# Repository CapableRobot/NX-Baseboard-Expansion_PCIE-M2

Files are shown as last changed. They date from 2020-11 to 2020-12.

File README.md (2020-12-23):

# NX Baseboard Expansion : PCIe m2 E-Key

This repository holds the open-source files for the PCIe m2 E-Key add-on to the NX Baseboard.  The [NX Baseboard](https://github.com/antmicro/jetson-nano-baseboard) is also open-source, is designed by Antmicro, and is [sold by Capable Robot Components](https://capablerobot.com/products/nx-baseboard/).

PCIe m2 E-Key PCBA

Assembled and tested PCBAs are available for purchase on the [Capable Robot website](https://capablerobot.com/products/nx-baseboard/).

The NX PCIe m.2 E Key PCB provides a standard interface to the NVIDIA NX's PCIe x1 bus, which is exposed on the NX Baseboard via a 10-pin FFC connector. Board specifications:

- m.2 E-Key (PCIe + USB), 2230 size. This is commonly used for WIFI modules like the Intel 8265.
- PCIe x1 interface and 3.3v power are connected to the Host via a 10-pin 0.5mm flex cable.
- USB interface exposed via micro-USB port, allowing USB-specific functionality of the installed card (like Bluetooth) to be used if cabled to the Host. With USB connected, a local 5v to 3.3v regulator can be used in lieu of the 3.3v input on the FFC connector.

Hole spacing on the PCB and location of the flex connector matches that of the NX Baseboard, allowing it to be assembled onto the bottom of the Baseboard.

Any WIFI module that supports m.2 E Key 2230 size can be used with the PCB. We recommend (and stock) the Intel 8265 due to built-in support within NVIDIA Jetpack BSPs.

## License Information

| **Type** | **License** |
| --- | --- |
| Hardware | Copyright Capable Robot Components 2020 <br><br>This source describes Open Hardware and is licensed under the [CERN-OHL-P v2](https://ohwr.org/cern_ohl_p_v2.txt). <br/><br/> You may redistribute and modify this documentation and make products using it under the terms of the [CERN-OHL-P v2](https:/cern.ch/cern-ohl). This documentation is distributed WITHOUT ANY EXPRESS OR IMPLIED WARRANTY, INCLUDING OF MERCHANTABILITY, SATISFACTORY QUALITY AND FITNESS FOR A PARTICULAR PURPOSE. Please see the CERN-OHL-P v2 for applicable conditions |
| Software | NA |
| Documentation | [Creative Commons Attribution-ShareAlike](https://creativecommons.org/licenses/by-sa/4.0/) License |

More detailed information about the CERN License is available in the [license](license) folder and on the [CERN website](https://ohwr.org/project/cernohl/wikis/home).

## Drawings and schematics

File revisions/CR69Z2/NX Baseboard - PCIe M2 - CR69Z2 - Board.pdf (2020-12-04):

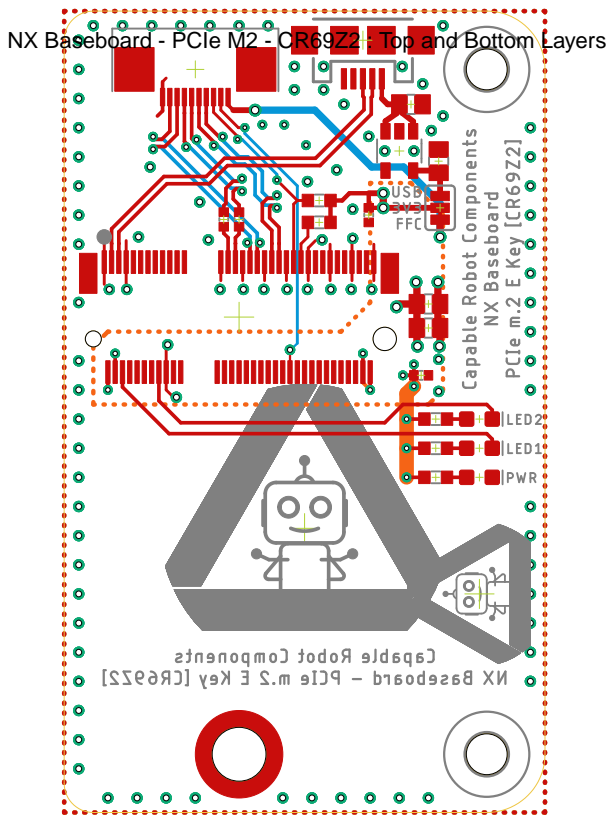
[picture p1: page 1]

NX Baseboard - PCIe M2 - CR69Z2 : Top and Bottom Layers

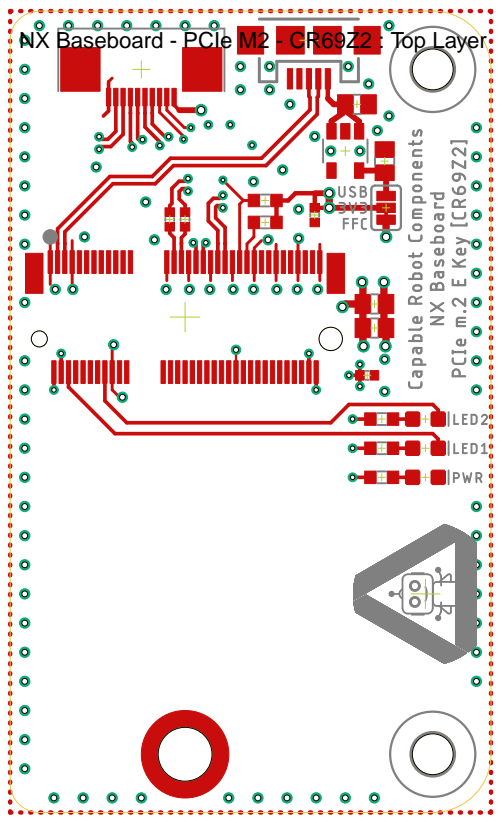
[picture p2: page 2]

NX Baseboard - PCIe M2 - CR69Z2 : Top Layer

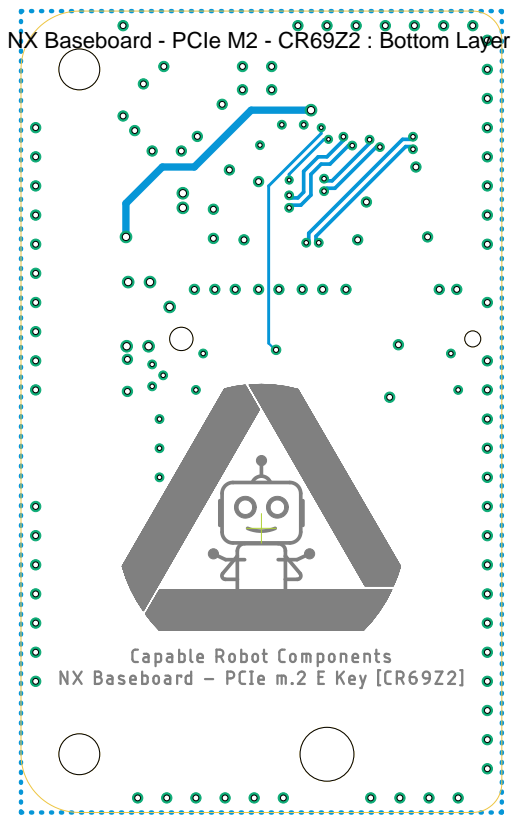
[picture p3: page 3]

NX Baseboard - PCIe M2 - CR69Z2 : Bottom Layer

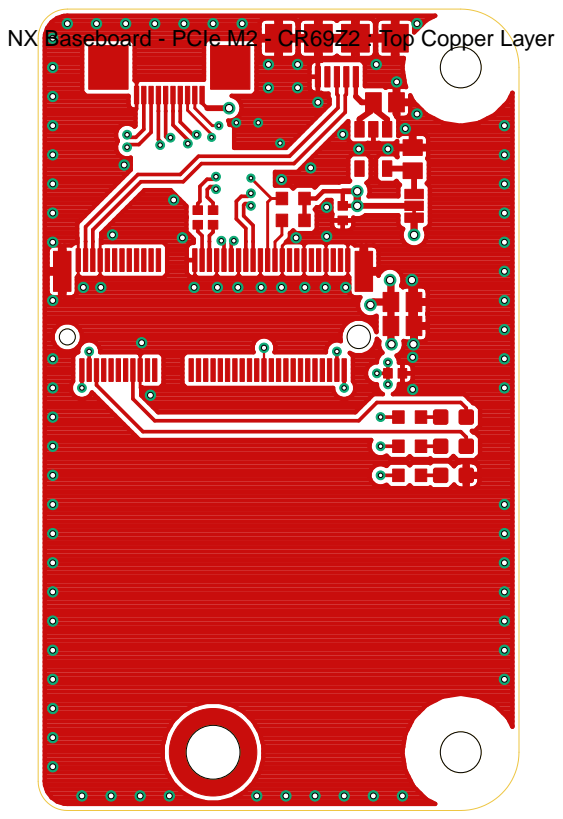
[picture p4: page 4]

NX Baseboard - PCIe M2 - CR69Z2 : Top Copper Layer

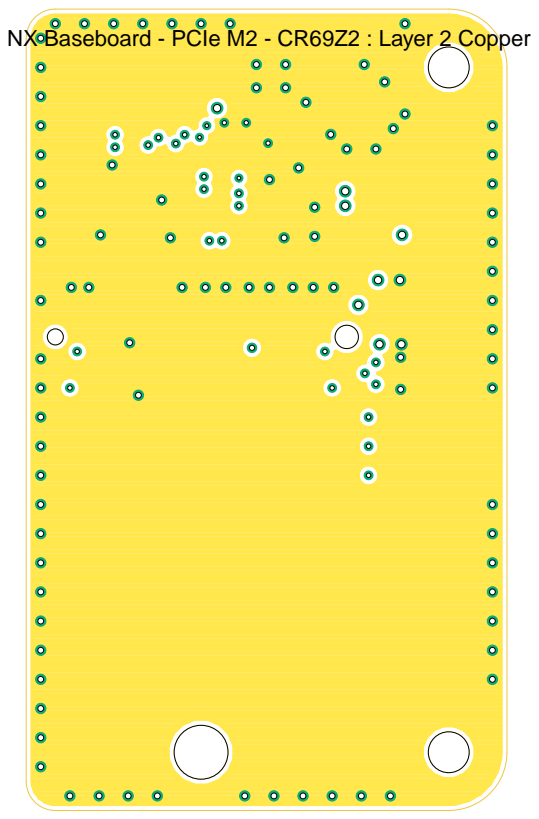
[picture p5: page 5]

NX Baseboard - PCIe M2 - CR69Z2 : Layer 2 Copper

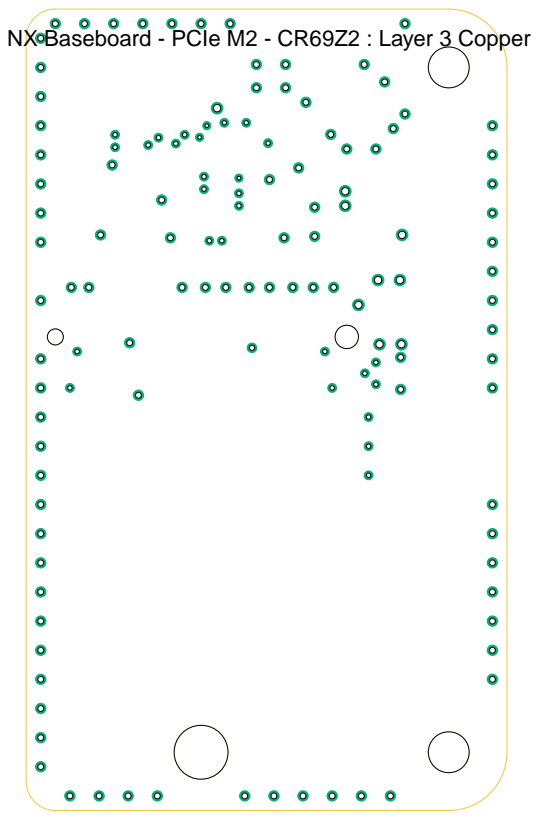
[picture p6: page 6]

NX Baseboard - PCIe M2 - CR69Z2 : Layer 3 Copper

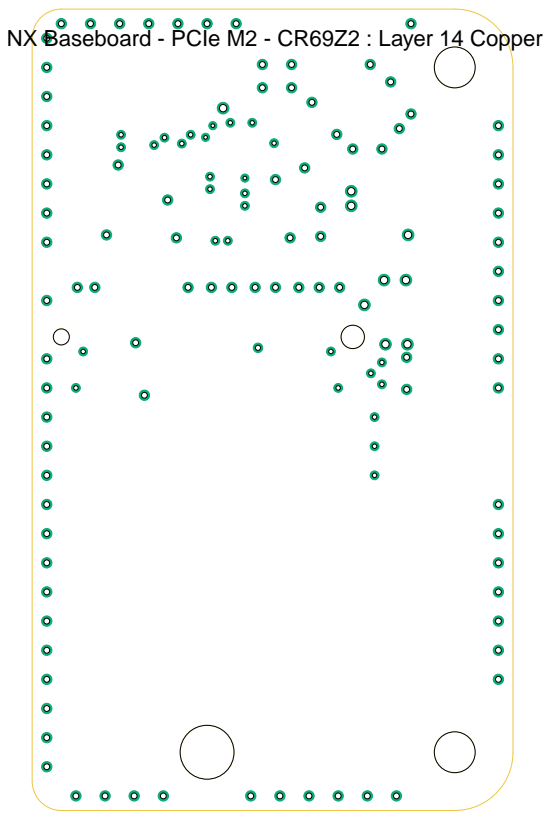
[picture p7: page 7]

NX Baseboard - PCIe M2 - CR69Z2 : Layer 14 Copper

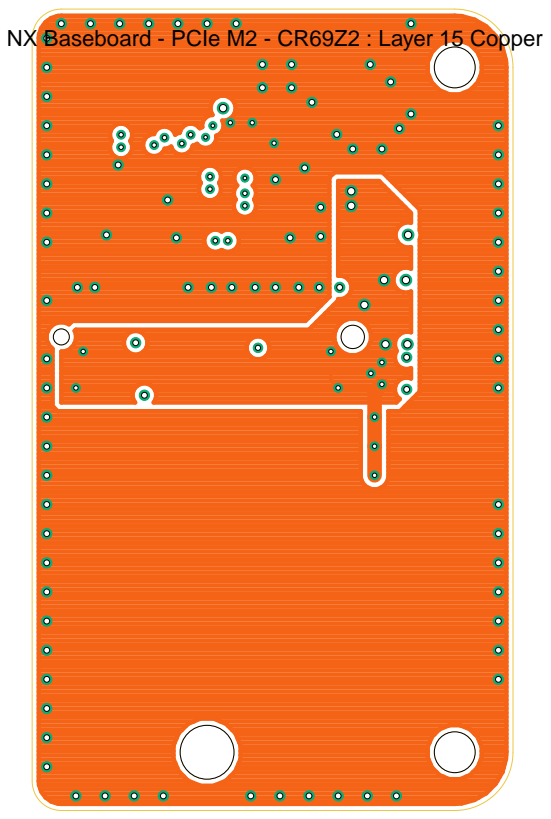
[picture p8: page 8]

NX Baseboard - PCIe M2 - CR69Z2 : Layer 15 Copper

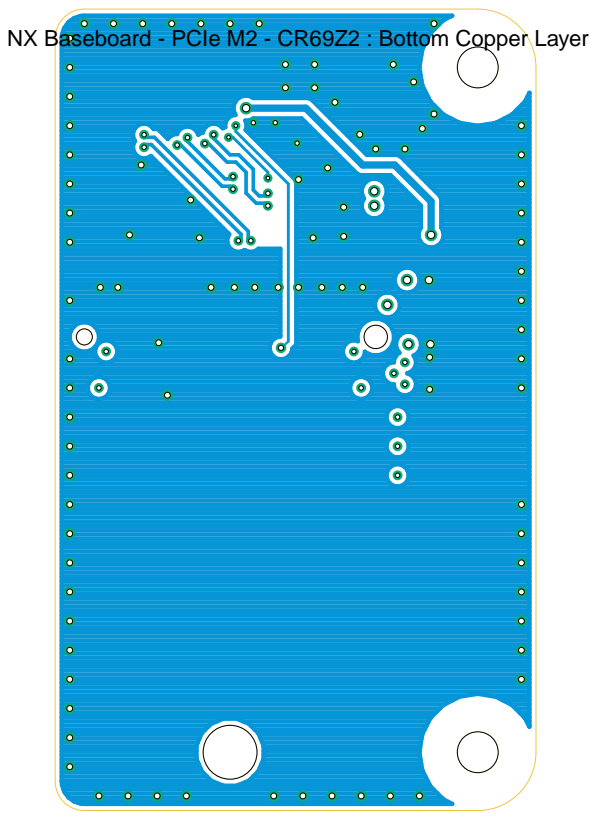
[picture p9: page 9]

NX Baseboard - PCIe M2 - CR69Z2 : Bottom Copper Layer

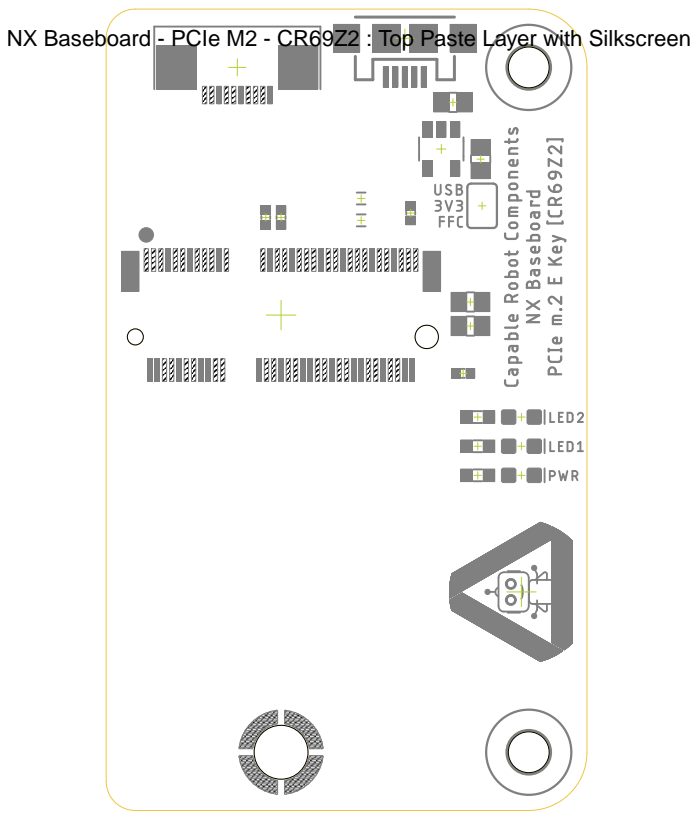
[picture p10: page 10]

NX Baseboard - PCIe M2 - CR69Z2 : Top Paste Layer with Silkscreen

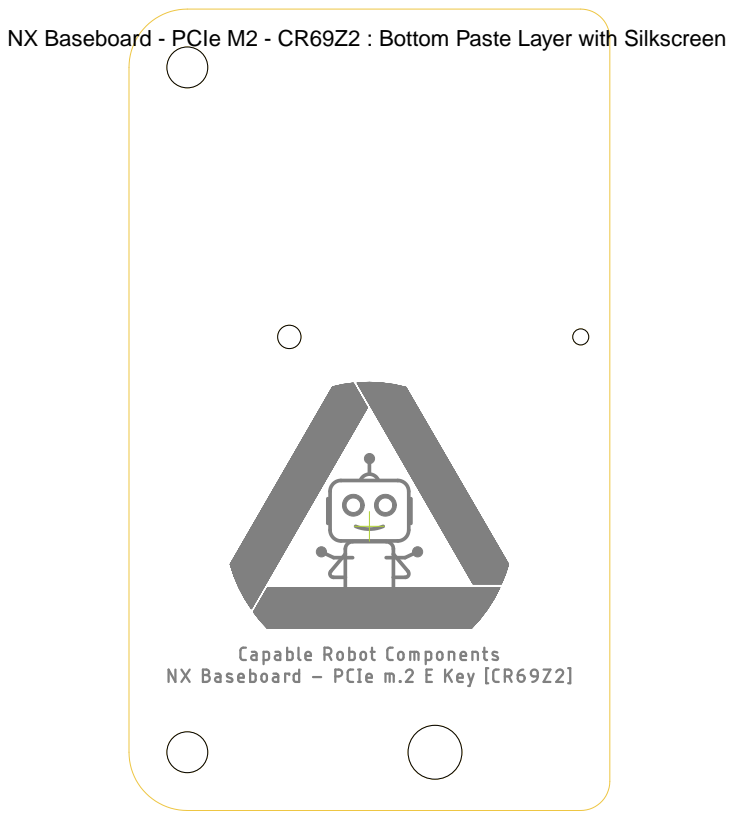
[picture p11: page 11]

NX Baseboard - PCIe M2 - CR69Z2 : Bottom Paste Layer with Silkscreen

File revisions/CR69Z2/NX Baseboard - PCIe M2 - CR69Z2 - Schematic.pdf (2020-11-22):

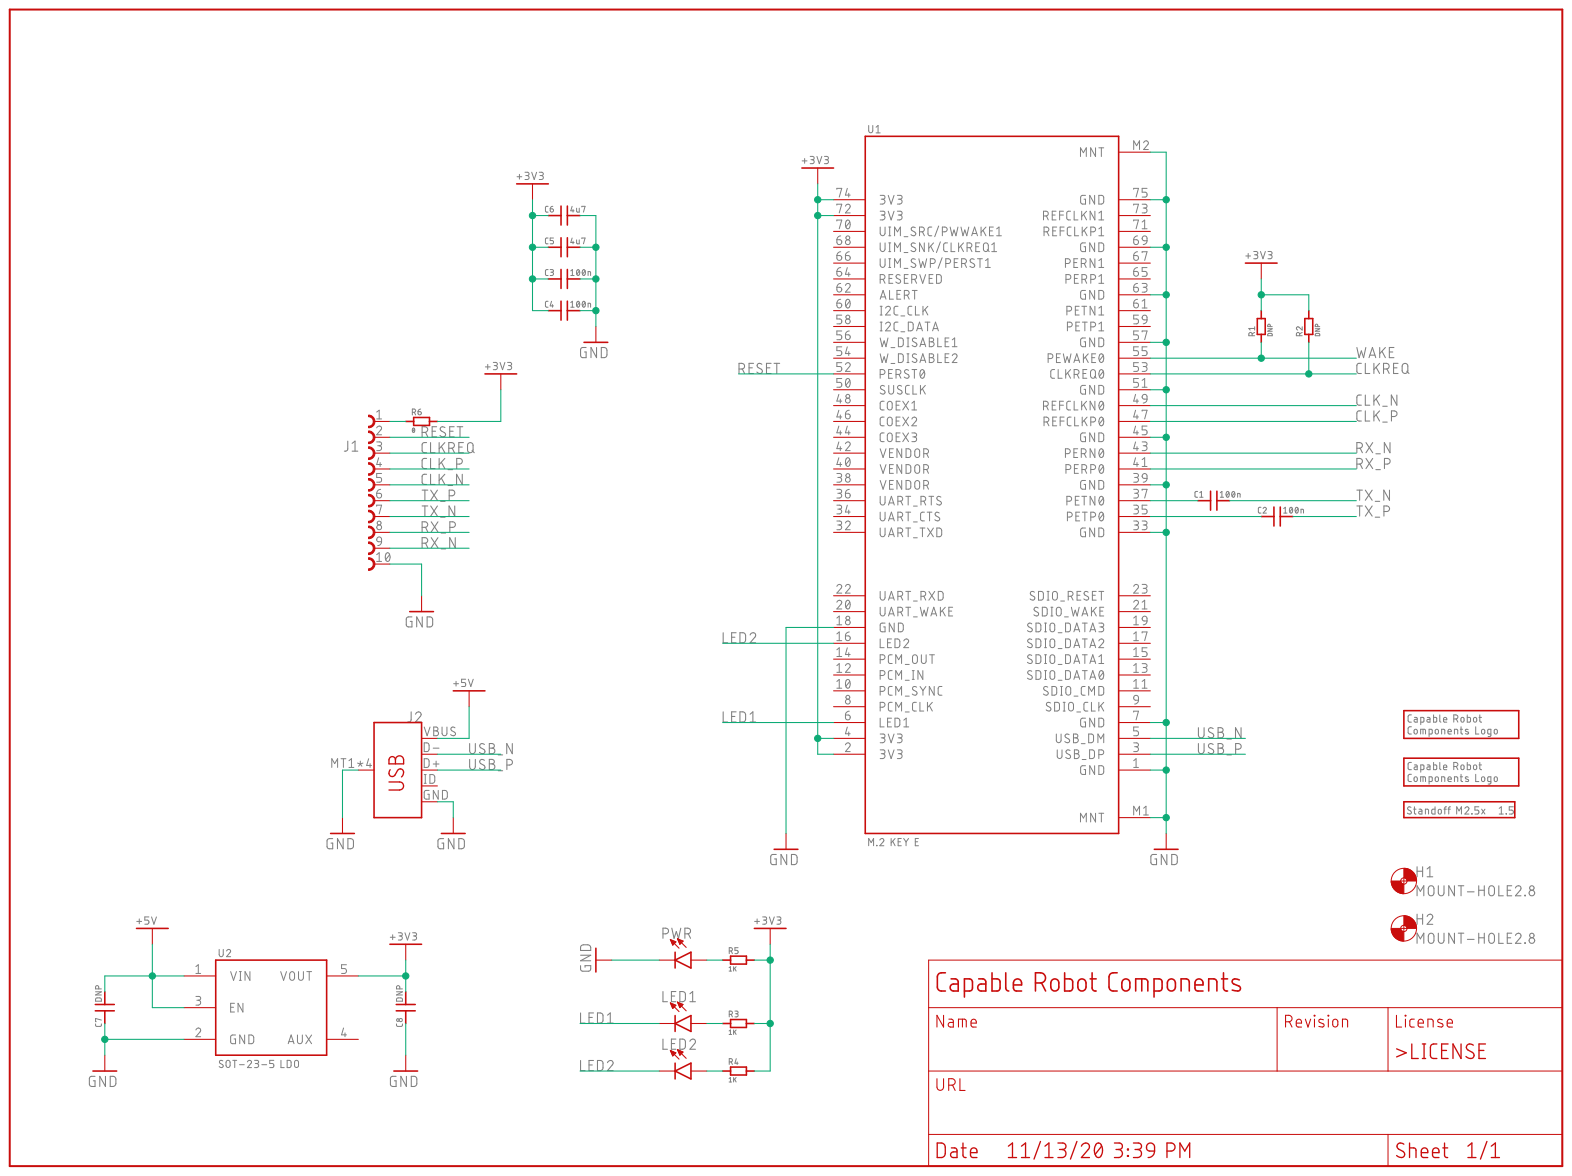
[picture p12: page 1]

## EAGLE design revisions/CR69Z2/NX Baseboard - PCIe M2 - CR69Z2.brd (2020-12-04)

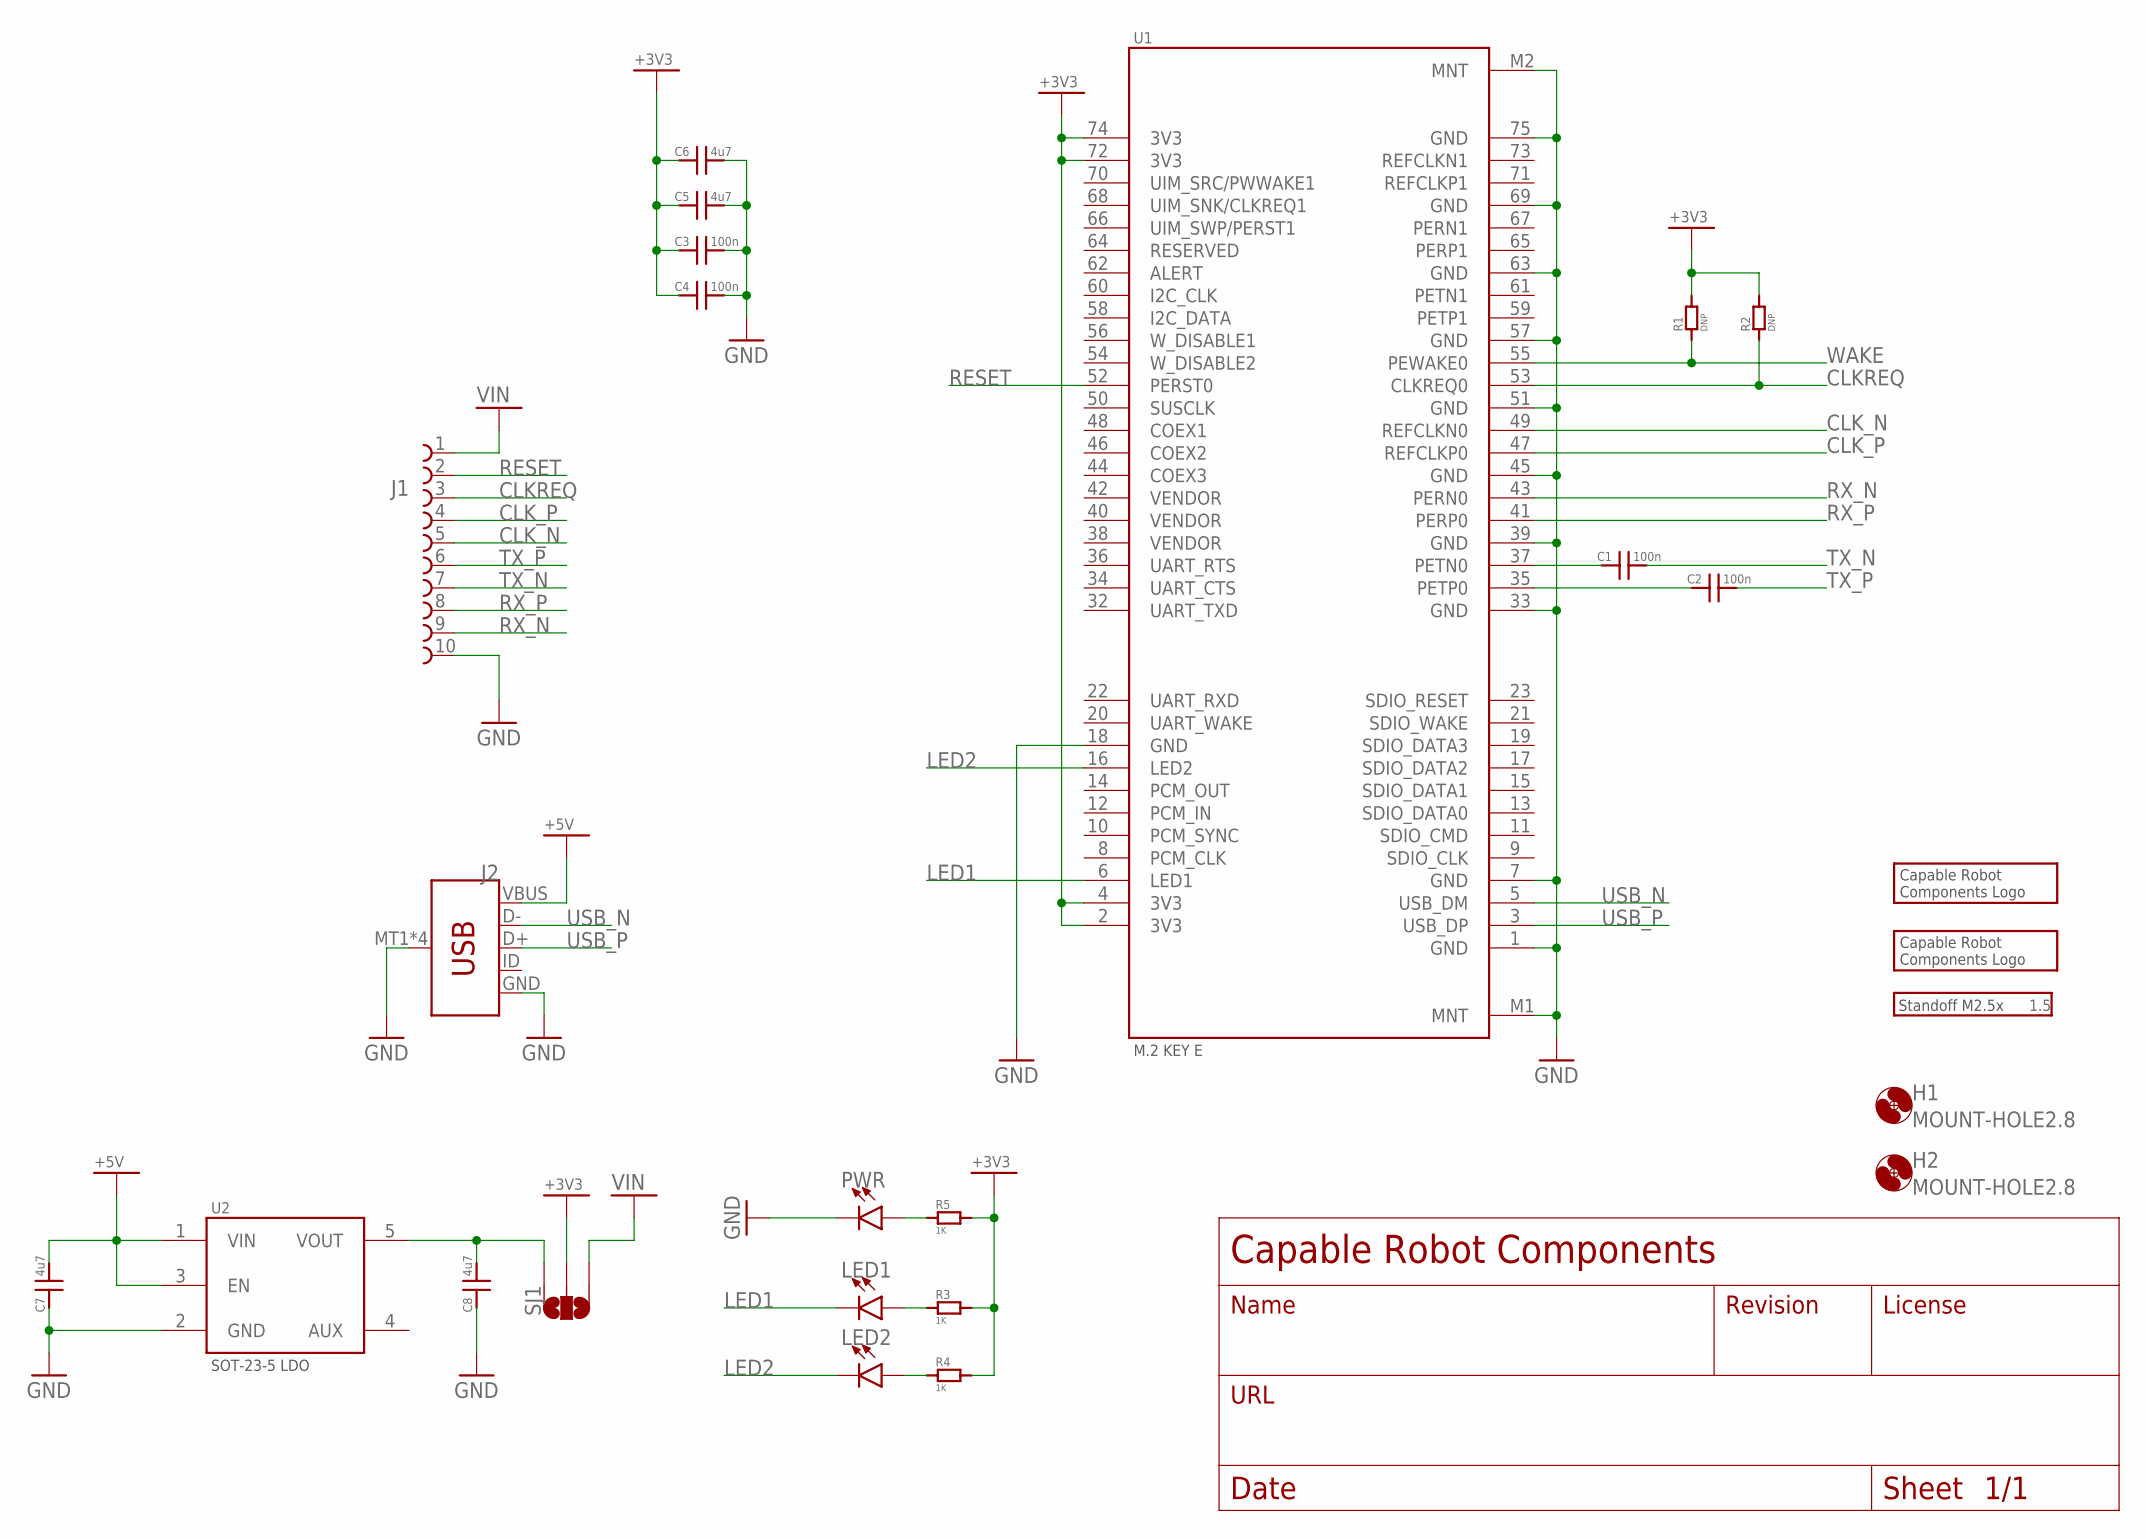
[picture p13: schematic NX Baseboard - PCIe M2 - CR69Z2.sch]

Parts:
C1, C2, C3, C4: 100n; 0402
C5, C6, C7, C8: 4u7; 0805
H1, H2: MOUNT-HOLE2.8; 2,8
J1: 68711014522
J2: USB_MICRO-B_SMT; USB-MICROB
LED1, LED2: LED0603; LED-0603
LOGO1: CRC-LOGO10SILK; CRC-LOGO-10-SILK
LOGO2: CRC-LOGO5SILK; CRC-LOGO-5-SILK
M1: 1.5; STANDOFF-M25; MPN 9774015151R
PWR: LED0603; LED-0603
R1, R2: DNP; 0603NOCREAM
R3, R4, R5: 1K; 0603
SJ1: JUMPER-PAD-3-NOYES_SILK; PAD-JUMPER-3-NO_YES_SILK
U1: M2-KEYE; TE-2199119-KEYE; MPN 2199119-4
U2: MIC20XX; SOT25

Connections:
+3V3: C3.1, C4.1, C5.1, C6.1, R1.2, R2.2, R3.2, R4.2, R5.2, SJ1.2, U1.2 (3V3), U1.4 (3V3), U1.72 (3V3), U1.74 (3V3)
+5V: C7.2, J2.VBUS, U2.1 (VIN), U2.3 (EN)
CLKREQ: J1.3, R2.1, U1.53 (CLKREQ0)
CLK_N: J1.5, U1.49 (REFCLKN0)
CLK_P: J1.4, U1.47 (REFCLKP0)
GND: C3.2, C4.2, C5.2, C6.2, C7.1, C8.1, J1.10, J2.GND, J2.MT1 (SHIELD), J2.MT2 (SHIELD), J2.P$1 (SHIELD), J2.P$2 (SHIELD), PWR.C, U1.1 (GND), U1.7 (GND), U1.18 (GND), U1.33 (GND), U1.39 (GND), U1.45 (GND), U1.51 (GND), U1.57 (GND), U1.63 (GND), U1.69 (GND), U1.75 (GND), U1.M1 (MNT), U1.M2 (MNT), U2.2 (GND)
LED1: LED1.C, U1.6 (LED1)
LED2: LED2.C, U1.16 (LED2)
M2_TX_N: C1.1, U1.37 (PETN0)
M2_TX_P: C2.1, U1.35 (PETP0)
unnamed: LED1.A, R3.1
unnamed: LED2.A, R4.1
unnamed: PWR.A, R5.1
RESET: J1.2, U1.52 (PERST0)
RX_N: J1.9, U1.43 (PERN0)
RX_P: J1.8, U1.41 (PERP0)
TX_N: C1.2, J1.7
TX_P: C2.2, J1.6
USB_N: J2.D-, U1.5 (USB_DM)
USB_P: J2.D+, U1.3 (USB_DP)
VIN: J1.1, SJ1.1
VREG: C8.2, SJ1.3, U2.5 (VOUT)
WAKE: R1.1, U1.55 (PEWAKE0)

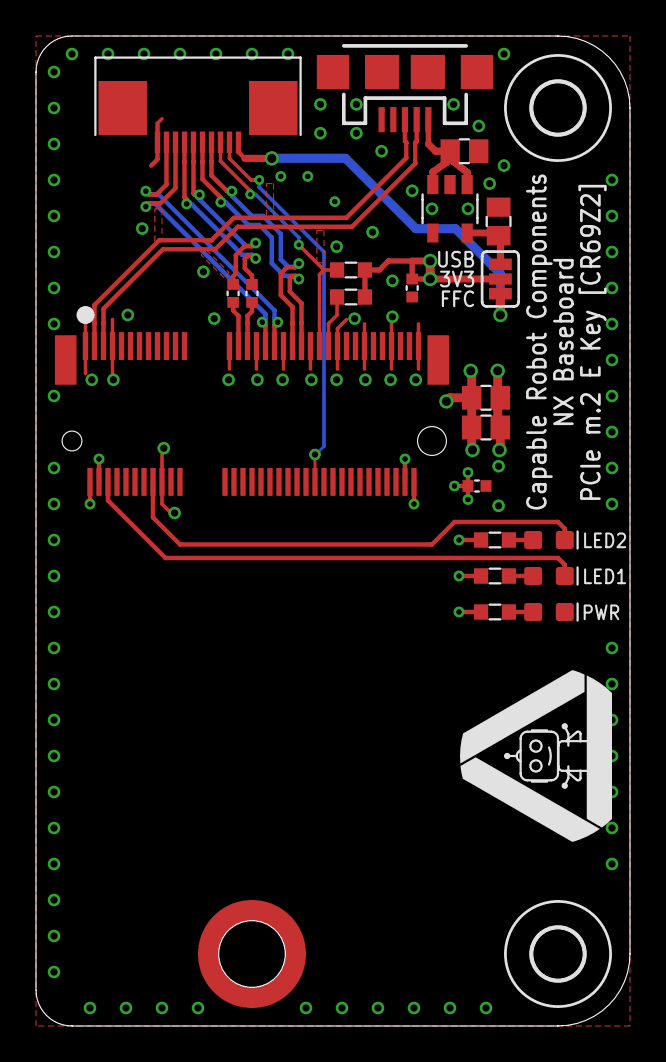
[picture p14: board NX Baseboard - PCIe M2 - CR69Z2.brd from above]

Board: 4 copper layers, 33.0 x 55.0 mm, 26 parts (1 on the bottom side), 23 nets.

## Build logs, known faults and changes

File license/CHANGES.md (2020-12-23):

Here we are compiling a community changelog.

If you come up with a modification of our designs, please share it
with the community, log your changes below, and upload the files to
our GitHub repository.

# Change Format

**Your name**
*Date*
Description of modification

# Change Log

* **Chris Osterwood** *2020-12-22* Initial release of CR69Z2.

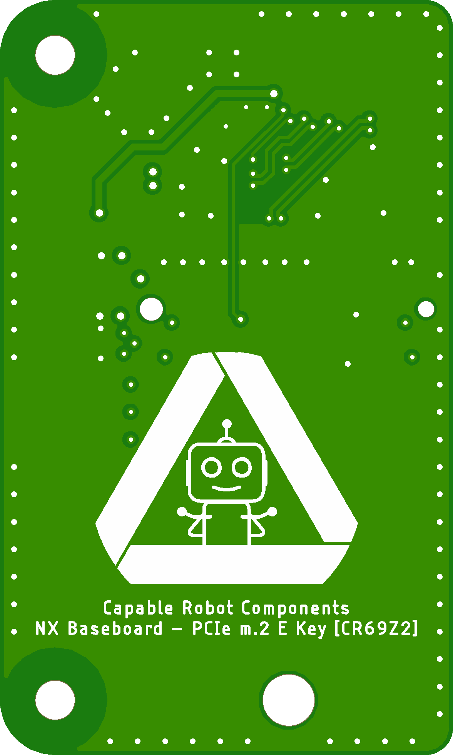
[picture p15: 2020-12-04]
revisions/CR69Z2/bottom.png

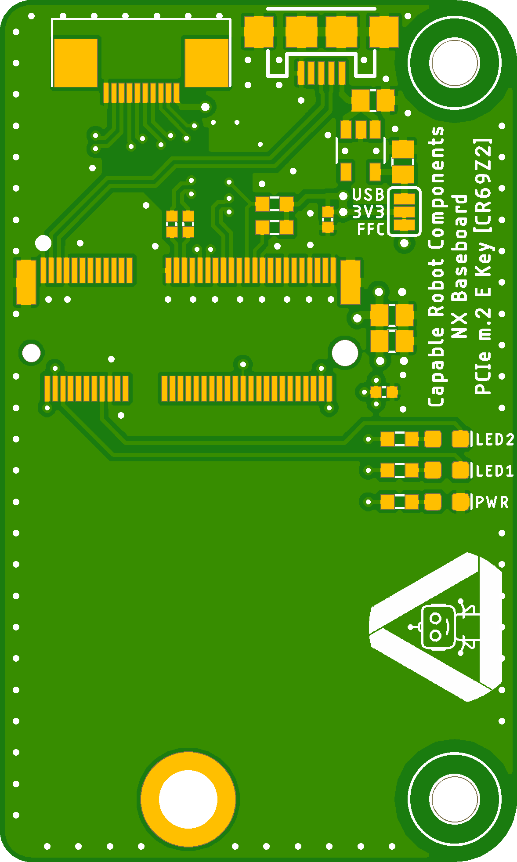
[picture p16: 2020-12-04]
revisions/CR69Z2/top.png

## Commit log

2020-11-22 Add initial release
    [NX Baseboard - PCIe M2 - CR69Z2.brd, NX Baseboard - PCIe M2 - CR69Z2.sch]
2020-12-04 Fix alignment hole size on M.2 footprint
    [NX Baseboard - PCIe M2 - CR69Z2.brd, NX Baseboard - PCIe M2 - CR69Z2.sch]
2020-12-04 Update exports after hole size change
    [NX Baseboard - PCIe M2 - CR69Z2.brd]

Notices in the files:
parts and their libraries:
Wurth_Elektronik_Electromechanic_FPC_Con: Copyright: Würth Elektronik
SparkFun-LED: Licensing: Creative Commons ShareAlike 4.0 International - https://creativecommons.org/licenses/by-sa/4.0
